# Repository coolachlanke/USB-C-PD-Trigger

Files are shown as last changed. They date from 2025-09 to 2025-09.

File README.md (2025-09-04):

# USB-C PD Trigger Board

## Overview
A custom 4-layer PCB for evaluating and triggering USB-C Power Delivery (PD) voltage profiles.  
The board combines an STM32F401RBT6 microcontroller with a Cypress CYPD3177 PD sink controller, enabling flexible control and monitoring of USB-C PD outputs.

## Features

- **USB-C Input**
  - Receptacle with differential pair routing for DFU support
  - CYPD3177 PD sink controller with I2C interface to MCU
  - Default PDO profile via resistor divider

- **Microcontroller**
  - STM32F401RBT6
  - SWD header for programming/debugging
  - USB DFU capability for easy firmware flashing
  - I2C communication with PD controller

- **User Interface**
  - Single pushbutton to cycle through PDOs
  - 5x yellow indicator LEDs for 5 V, 9 V, 12 V, 15 V, 20 V

- **Connectivity**
  - VOUT terminal block for load connection
  - UART header (TX/RX) for serial monitoring

- **Debug/Monitoring**
  - Testpoints for VIN, VOUT, and GND

## Engineering Notes

- **Stackup:** 4 layers  
  - L1: Signal  
  - L2: Solid GND plane  
  - L3: Power plane  
  - L4: Signal

- **Differential Pair Routing (D+/D−)**
  - ~35 mm trace length  
  - ~0.9 mm mismatch (acceptable for USB Full Speed)  
  - Routed mainly on bottom layer with coplanar GND pour

- **Grounding**
  - Full-plane GND layers with stitching vias for shielding  
  - Top and bottom copper filled with GND pours

## Manufacturing
- Gerbers, BOM, and CPL generated using the [JLCPCB KiCad plugin](https://github.com/Bouni/kicad-jlcpcb-tools)
- Board ready for fabrication via JLCPCB  

## Future Development
- Develop firmware and config scripts for STM32
- Test power delivery with electronic load
- Use USB-C tester to test selected profile
- Add UART command interface for PDO selection  
- Expand to higher-speed USB signaling support

## Render

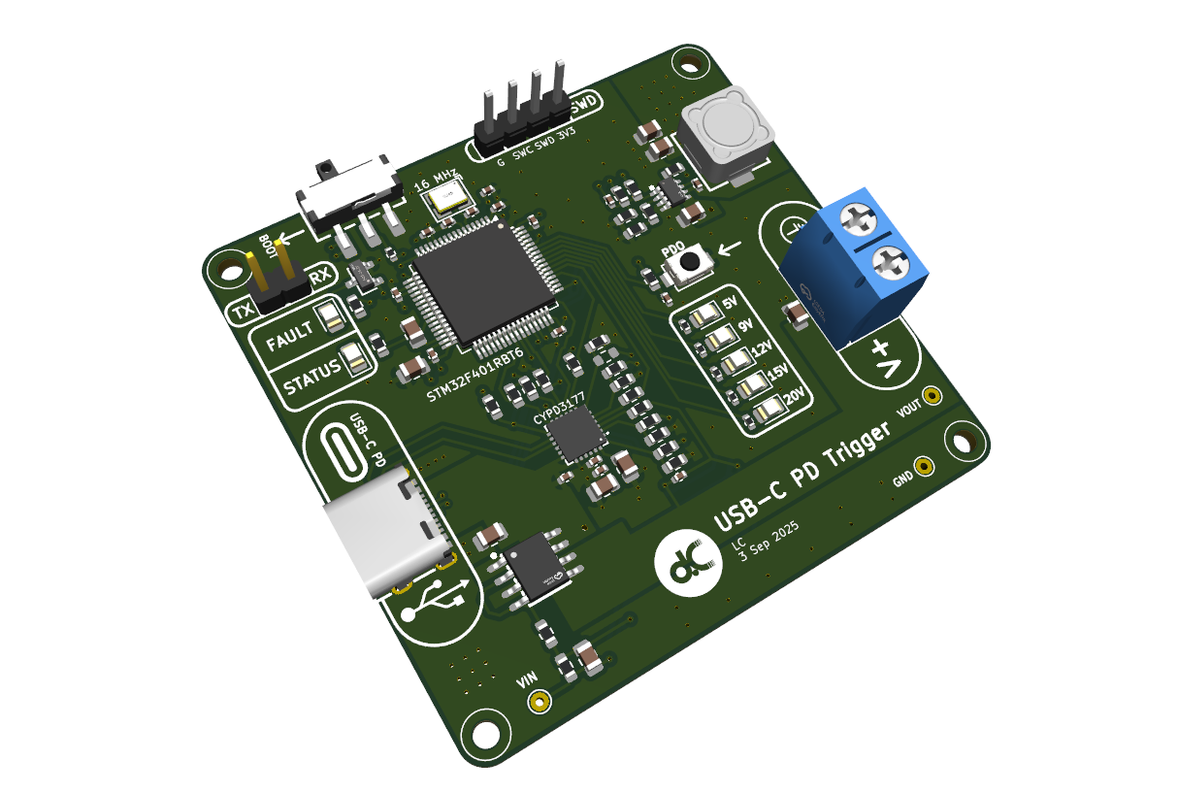
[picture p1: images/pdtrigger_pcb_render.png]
USB-C PD Trigger Board


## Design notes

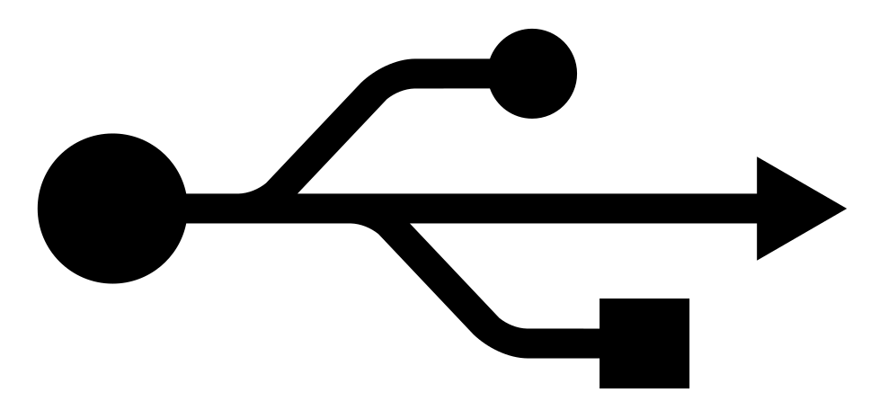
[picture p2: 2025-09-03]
images/usb.png

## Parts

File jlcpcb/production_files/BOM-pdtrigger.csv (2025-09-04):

Comment | Designator | Footprint | LCSC | Quantity
16MHz | Y1 | OSC-SMD_4P-L3.2-W2.5-BL | C13738 | 1
100n | C1,C13,C15,C16,C18,C22,C3,C4,C5,C6,C7,C8 | C_0402_1005Metric | C1525 | 12
4.7u | C12,C14,C17,C19,C2,C20,C21,C23,C24,C9 | C_0805_2012Metric | C1779 | 10
47u | L1 | IND-SMD_L7.3-W7.3 | C216198 | 1
YEL | D3,D4,D5,D6,D7 | LED_0805_2012Metric | C2296 | 5
10k | R2 | R_0402_1005Metric | C25744 | 1
1k5 | R28,R29,R30,R31,R32 | R_0402_1005Metric | C25867 | 5
Conn_01x04_Pin | J1 | HDR-TH_4P-P2.54-V-M | C2691448 | 1
USB_C_Receptacle_USB2.0_16P | J2 | NEW_USB-C-SMD_TYPE-C-6PIN-2MD-073 | C2765186 | 1
CYPD3177-24LQXQ | U2 | TQFN-24_L4.0-W4.0-P0.50-TL-EP2.8 | C2959321 | 1
10p | C10,C11,C25 | C_0402_1005Metric | C32949 | 3
20k | R11,R17,R21,R22,R23,R24,R25,R27 | R_0603_1608Metric | C4184 | 8
2k2 | R1,R12,R13,R14,R15,R16,R18,R19,R20,R26,R3,R4,R5,R6,R7,R8,R9 | R_0603_1608Metric | C4190 | 17
TERM_BLK | U3 | CONN-TH_P5.00_KF301-5.0-2P | C474881 | 1
Conn_01x02_Pin | J3 | HDR-TH_2P-P2.54-V-M | C492401 | 1
1u | C26 | C_0402_1005Metric | C52923 | 1
DMP3098LSD-13 | Q1 | SO-8_L4.9-W3.9-P1.27-LS5.9-BL | C531177 | 1
SW_Push | SW2 | SW-SMD_L3.9-W3.0-P4.45 | C720477 | 1
STM32F401RBT6 | U1 | LQFP-64_10x10mm_P0.5mm | C74524 | 1
RED | D1,D2 | LED_0805_2012Metric | C84256 | 2
NMOS | Q3 | SOT-23-3_L2.9-W1.3-P1.90-LS2.4-BR | C8545 | 1
SW_SPDT | SW1 | SW-SMD_K3-1280S-K1 | C92658 | 1
SY8303AIC | U4 | TSOT-23-8_L2.9-W1.6-P0.65-LS2.8-BR | C97054 | 1
TestPoint | TP3 | TestPoint_THTPad_D1.5mm_Drill0.7mm |  | 1
TestPoint | TP2 | TestPoint_THTPad_D1.5mm_Drill0.7mm |  | 1
TestPoint | TP1 | TestPoint_THTPad_D1.5mm_Drill0.7mm |  | 1

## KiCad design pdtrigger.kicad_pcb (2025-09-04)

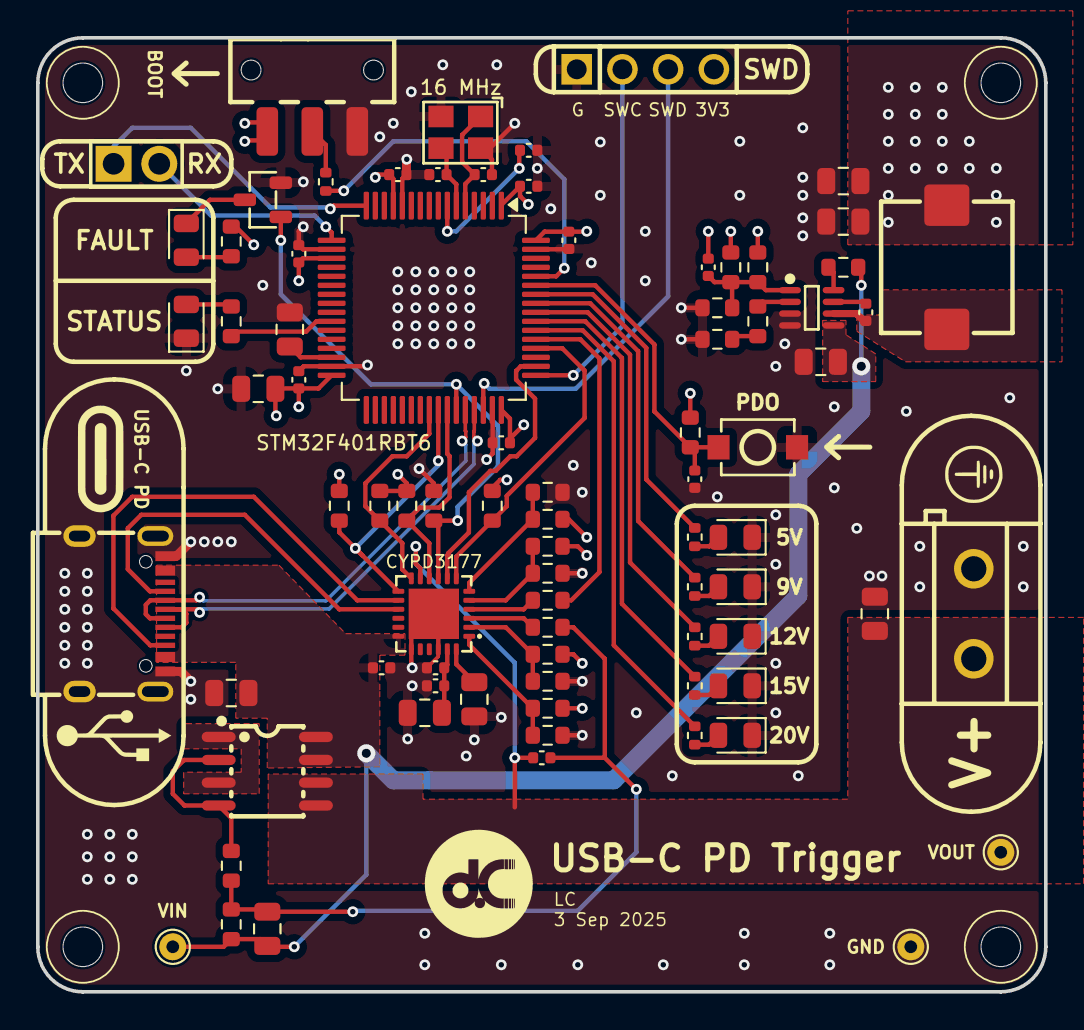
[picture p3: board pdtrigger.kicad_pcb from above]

Board: 4 copper layers, 56.0 x 53.0 mm, 85 parts (0 on the bottom side), 57 nets.

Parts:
C1, C3, C4, C5, C6, C7, C8, C13, C15, C16, C18, C22: 100n; C_0402_1005Metric
C2, C9, C12, C14, C17, C19, C20, C21, C23, C24: 4.7u; C_0805_2012Metric
C10, C11, C25: 10p; C_0402_1005Metric
C26: 1u; C_0402_1005Metric
D1, D2: RED; LED_0805_2012Metric
D3, D4, D5, D6, D7: YEL; LED_0805_2012Metric
H1, H2, H3, H4: MountingHole; MountingHole_2.2mm_M2
J1: Conn_01x04_Pin; HDR-TH_4P-P2.54-V-M
J2: USB_C_Receptacle_USB2.0_16P; NEW_USB-C-SMD_TYPE-C-6PIN-2MD-073
J3: Conn_01x02_Pin; HDR-TH_2P-P2.54-V-M
L1: 47u; IND-SMD_L7.3-W7.3
Q1: DMP3098LSD-13; SO-8_L4.9-W3.9-P1.27-LS5.9-BL
Q3: NMOS; SOT-23-3_L2.9-W1.3-P1.90-LS2.4-BR
R1, R3, R4, R5, R6, R7, R8, R9, R12, R13, R14, R15, R16, R18, R19, R20, R26: 2k2; R_0603_1608Metric
R2: 10k; R_0402_1005Metric
R10: DNP; R_0603_1608Metric
R11, R17, R21, R22, R23, R24, R25, R27: 20k; R_0603_1608Metric
R28, R29, R30, R31, R32: 1k5; R_0402_1005Metric
SW1: SW_SPDT; SW-SMD_K3-1280S-K1
SW2: SW_Push; SW-SMD_L3.9-W3.0-P4.45
TP1, TP2, TP3: TestPoint; TestPoint_THTPad_D1.5mm_Drill0.7mm
U1: STM32F401RBT6; LQFP-64_10x10mm_P0.5mm
U2: CYPD3177-24LQXQ; TQFN-24_L4.0-W4.0-P0.50-TL-EP2.8
U3: TERM_BLK; CONN-TH_P5.00_KF301-5.0-2P
U4: SY8303AIC; TSOT-23-8_L2.9-W1.6-P0.65-LS2.8-BR
Y1: 16MHz; OSC-SMD_4P-L3.2-W2.5-BL

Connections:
+3V3: C14.1, C15.1, C16.1, U2.23 (VDDD)
+3V3_MCU: C3.1, C4.1, C5.1, C6.1, C7.1, C8.1, C9.1, C23.1, C24.1, C25.1, J1.4, L1.2, R3.1, R5.1, R7.1, R10.1, R12.1, R13.1, R14.1, R18.1, R19.1, R24.1, R25.1, R27.1, SW1.1 (A), U1.1 (VBAT), U1.13 (VREF+), U1.19 (VDD), U1.32 (VDD), U1.48 (VDD), U1.64 (VDD)
/BOOT0: R2.2, U1.60 (BOOT0)
/BUCK_FB: C25.2, R24.2, R25.2, R26.1, U4.1 (FB)
/BUCK_FS: R22.1, U4.2 (FS)
/CC1: J2.A5 (CC1), U2.15 (CC1)
/CC2: J2.B5 (CC2), U2.14 (CC2)
/HSE_IN: C10.1, U1.5 (PH0), Y1.1
/HSE_OUT: C11.1, U1.6 (PH1), Y1.3
/I2C3_SCL: R13.2, U1.41 (PA8), U2.13 (HPI_SCL)
/I2C3_SDA: R14.2, U1.40 (PC9), U2.12 (HPI_SDA)
/ISINK_COAR: R7.2, R8.1, U2.5 (ISNK_COARSE)
/ISINK_FINE: R9.1, R10.2, U2.6 (ISNK_FINE)
/LED_PDO1: R28.1, U1.58 (PB6)
/LED_PDO2: R29.1, U1.57 (PB5)
/LED_PDO3: R30.1, U1.56 (PB4)
/LED_PDO4: R31.1, U1.55 (PB3)
/LED_PDO5: R32.1, U1.54 (PD2)
/LOAD_SOURCE: Q1.1 (S1), Q1.3 (S2)
/LX: C22.2, L1.1, U4.6 (LX)
/MODE_BTN: C26.1, R27.2, SW2.2, U1.59 (PB7)
/NRST: C1.1, U1.7 (NRST)
/PDC_VCCD: C17.1, U2.24 (VCCD)
/PD_FAULT: Q3.2 (G), R11.1, U1.43 (PA10), U2.9 (FAULT)
/PD_FLIP: R19.2, U1.42 (PA9), U2.10 (FLIP)
/PD_GPIO: U1.50 (PA15), U2.8 (GPIO_1)
/PD_INT: R18.2, U1.52 (PC11), U2.7 (HPI_INT)
/PD_SAFE: R20.1, U1.53 (PC12)
/SAFE_PWR_EN: R20.2, U2.4 (SAFE_PWR_EN)
/STATUS_LED: R1.1, U1.26 (PB0)
/SWCLK: J1.2, U1.49 (PA14)
/SWDIO: J1.3, U1.46 (PA13)
/SW_BOOT0: R2.1, SW1.2 (B)
/UART_RX: J3.2, U1.17 (PA3)
/UART_TX: J3.1, U1.16 (PA2)
/USB_D+: J2.A6 (D+), J2.B6 (D+), U1.45 (PA12)
/USB_D-: J2.A7 (D-), J2.B7 (D-), U1.44 (PA11)
/VBUS: C12.1, C13.1, C19.1, C21.1, J2.A4 (VBUS), J2.A9 (VBUS), J2.B4 (VBUS), J2.B9 (VBUS), Q1.7 (D1), Q1.8 (D1), R17.1, R21.1, TP3.1, U2.18 (VBUS_IN), U4.5 (IN)
/VBUS_FET_EN: R16.2, U2.3 (VBUS_FET_EN)
/VBUS_MAX: R3.2, R4.1, U2.2 (VBUS_MAX)
/VBUS_MIN: R5.2, R6.1, U2.1 (VBUS_MIN)
/VCAP1: C2.1, U1.30 (VCAP1)
/V_BUS_OUT: C18.1, C20.1, Q1.5 (D2), Q1.6 (D2), TP1.1, U2.11 (VDC_OUT), U3.1
GND: C1.2, C2.2, C3.2, C4.2, C5.2, C6.2, C7.2, C8.2, C9.2, C10.2, C11.2, C12.2, C13.2, C14.2, C15.2, C16.2, C17.2, C20.2, C21.2, C23.2, C24.2, C26.2, D1.1 (K), D3.1 (K), D4.1 (K), D5.1 (K), D6.1 (K), D7.1 (K), J1.1, J2.A1 (GND), J2.A12 (GND), J2.B1 (GND), J2.B12 (GND), J2.S1 (SHIELD), Q3.3 (S), R4.2, R6.2, R8.2, R9.2, R11.2, R23.2, R26.2, SW1.3 (C), SW2.1, TP2.1, U1.12 (VSSA), U1.18 (VSS), U1.31 (VSS), U1.47 (VSS), U1.63 (VSS), U2.19 (GND), U2.22 (GND), U2.25 (EPAD), U3.2, U4.3 (GND), U4.4 (GND), Y1.2, Y1.4
unnamed: C18.2, C19.2, R15.2, R16.1, R17.2
unnamed: D1.2 (A), R1.2
unnamed: D2.2 (A), R12.2
unnamed: D2.1 (K), Q3.1 (D)
unnamed: D3.2 (A), R28.2
unnamed: D4.2 (A), R29.2
unnamed: D5.2 (A), R30.2
unnamed: D6.2 (A), R31.2
unnamed: D7.2 (A), R32.2
unnamed: Q1.2 (G1), Q1.4 (G2), R15.1
unnamed: R22.2, R23.1
unnamed: C22.1, U4.7 (BS)
unnamed: R21.2, U4.8 (EN)

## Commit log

2025-09-01 Initial ICs and passives
    [pdtrigger.kicad_sch]
2025-09-01 70% finished with component selection and schem entry
    [pdtrigger.kicad_sch]
2025-09-01 Final wiring before leaving office
    [pdtrigger.kicad_sch]
2025-09-03 Board ready for routing
    [pdtrigger.kicad_pcb]
2025-09-04 Cleaned up schem
    [BOM-pdtrigger.csv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]
